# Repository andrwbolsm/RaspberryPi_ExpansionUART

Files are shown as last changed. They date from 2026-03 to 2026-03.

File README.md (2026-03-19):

 
## Context
 
The Raspberry Pi exposes only one hardware UART, which is insufficient when simultaneous communication with multiple devices is required. In this project, each drone in a six-drone swarm uses a dedicated 433 MHz radio transceiver connected over UART. To handle six transceivers from a single Raspberry Pi, a custom expansion board (HAT) was designed using the SC16IS752, natively supported by Linux.
 
A key motivation for moving away from USB was power delivery: the Raspberry Pi's USB ports do not supply enough current to reliably drive multiple radio modules, even through powered hubs. Bypassing USB in favour of direct UART with battery-sourced power resolves this limitation.
 
---
 
## System Architecture
 
```
[ Battery ]
     │
     ├──► [ Voltage Regulator (5V) ] ──► [ SC16IS752 ]
     │                                        │
[ Raspberry Pi ]                       UART A (/dev/ttySC0) ──► Radio transceiver 1
  I²C bus ──────────────────────────►  UART B (/dev/ttySC1) ──► Radio transceiver 2
                                        (stack additional chips for more channels)
```
 
- Power for the SC16IS752 is drawn **directly from the battery** through a regulator, bypassing the Raspberry Pi's USB current limit.
- The I²C bus from the Raspberry Pi controls the chip; Linux automatically exposes each UART as `/dev/ttySC0` and `/dev/ttySC1`.
- Multiple chips can be stacked on the same I²C bus using different A0/A1 addresses, scaling up to 32 UART channels.
 
---
 
## Hardware
 
| Component | Role |
|---|---|
| Raspberry Pi | Main onboard computer (Linux) |
| SC16IS752 | I²C-to-dual-UART bridge chip (2 ch UART + 8 GPIO) |
| 433 MHz radio transceivers | Long-range communication with drones (~400 m through buildings) |
| Voltage regulator | Supplies 5V (≥ 1W) to the chip from the battery |
| Custom HAT PCB | Designed with KiCad; connects directly to the Raspberry Pi GPIO header |
 
The radio modules operate in the **433 MHz band**, each assigned a separate channel to avoid inter-drone interference.
 
---
 
## Repository Structure
 
```
.
├── Code/               # Firmware / communication validation code (C)
├── Projet_Tschema/     # PCB schematic and layout files (KiCad)
└── README.md
```
 
---
 
## Setup
 
### 1. Enable I²C on the Raspberry Pi
 
```bash
sudo raspi-config
# Navigate to: Interfacing Options → I2C → Yes
```
 
### 2. Register the SC16IS752 kernel driver
 
Append to `/boot/config.txt`:
 
```
dtoverlay=sc16is752-i2c,int_pin=24,addr=0x48
# addr changes according to A0/A1 jumper setting — default is 0x48
```
 
Then reboot:
 
```bash
sudo reboot
```
 
### 3. Verify UART devices are exposed
 
```bash
ls /dev/ttySC*
# Expected: /dev/ttySC0  /dev/ttySC1
```
 
---
 
## PCB Design
 
The expansion board is designed in **KiCad** (files in `Projet_Tschema/`). It plugs onto the Raspberry Pi GPIO header and provides:
 
- I²C connection to the SC16IS752
- Battery-sourced regulated 5V power rail for the chip
- UART connectors for each radio transceiver
   
---
 
## Software
 
The firmware (`Code/`, C) handles:
 
1. **UART validation** — confirms Linux correctly enumerates `/dev/ttySC0` and `/dev/ttySC1` after the HAT is mounted.
2. **Communication protocol** — data exchange with each radio transceiver over its dedicated UART channel.
 
---

## Validation Steps
 
1. Mount the HAT and power the SC16IS752 from the battery rail.
2. Confirm UART devices appear: `ls /dev/ttySC*`
3. Run the communication test to validate send/receive on one channel.
 
---
 
## Status
 
> Active development — PCB validation and multi-channel firmware in progress.

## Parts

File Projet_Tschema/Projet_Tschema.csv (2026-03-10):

Reference | Qty | Value | DNP | Exclude from BOM | Exclude from Board | Footprint | Datasheet
C1 | 1 | 0.1uF |  |  |  | Capacitor_SMD:C_0805_2012Metric | ~
C2 | 1 | 22pF |  |  |  | Capacitor_SMD:C_0805_2012Metric | ~
C3 | 1 | 33pF |  |  |  | Capacitor_SMD:C_0805_2012Metric | ~
C4,C5 | 2 | 10uF |  |  |  | Capacitor_SMD:C_0805_2012Metric | ~
D1,D2 | 2 | LED_Filled |  |  |  | LED_SMD:LED_0805_2012Metric | ~
H1,H2 | 2 | Conn_01x06 |  |  |  | Connector_JST:JST_GH_SM06B-GHS-TB_1x06-1MP_P1.25mm_Horizontal | ~
J1 | 1 | Raspberry_Pi_2_3 |  |  |  | Connector_PinHeader_2.54mm:PinHeader_2x20_P2.54mm_Vertical | https://www.raspberrypi.org/documentation/hardware/raspberrypi/schematics/rpi_SCH_3bplus_1p0_reduced.pdf
J2 | 1 | Screw_Terminal_01x02 |  |  |  | Connector_PinHeader_2.54mm:PinHeader_1x02_P2.54mm_Vertical | ~
J3 | 1 | Conn_D42V55F5 |  |  |  | Connector_PinHeader_2.54mm:PinHeader_2x06_P2.54mm_Vertical | ~
L_RXA1,L_RXB1,L_TXA1,L_TXB1 | 4 | LED_Filled |  |  |  | Resistor_SMD:R_0805_2012Metric | ~
R1,R3,R4,R5,R8,R9,R10,R24 | 8 | 1K |  |  |  | Resistor_SMD:R_0805_2012Metric | ~
R2 | 1 | 10K |  |  |  | Resistor_SMD:R_0805_2012Metric | ~
R11,R12,R13 | 3 | 0R |  |  |  | Resistor_SMD:R_0805_2012Metric | ~
R14,R15,R16,R17,R18,R19,R20,R21,R22,R23 | 10 | NC |  |  |  | Resistor_SMD:R_0805_2012Metric | ~
U1 | 1 | SC16IS-752 |  |  |  | Package_SO:TSSOP-28_4.4x9.7mm_P0.65mm | https://www.nxp.com/docs/en/data-sheet/SC16IS752_SC16IS762.pdf
U2 | 1 | AMS1117 |  |  |  | Package_TO_SOT_SMD:SOT-223-3_TabPin2 | http://www.advanced-monolithic.com/pdf/ds1117.pdf
Y1 | 1 | 14.7456M |  |  |  | Crystal:Crystal_SMD_3225-4Pin_3.2x2.5mm | ~

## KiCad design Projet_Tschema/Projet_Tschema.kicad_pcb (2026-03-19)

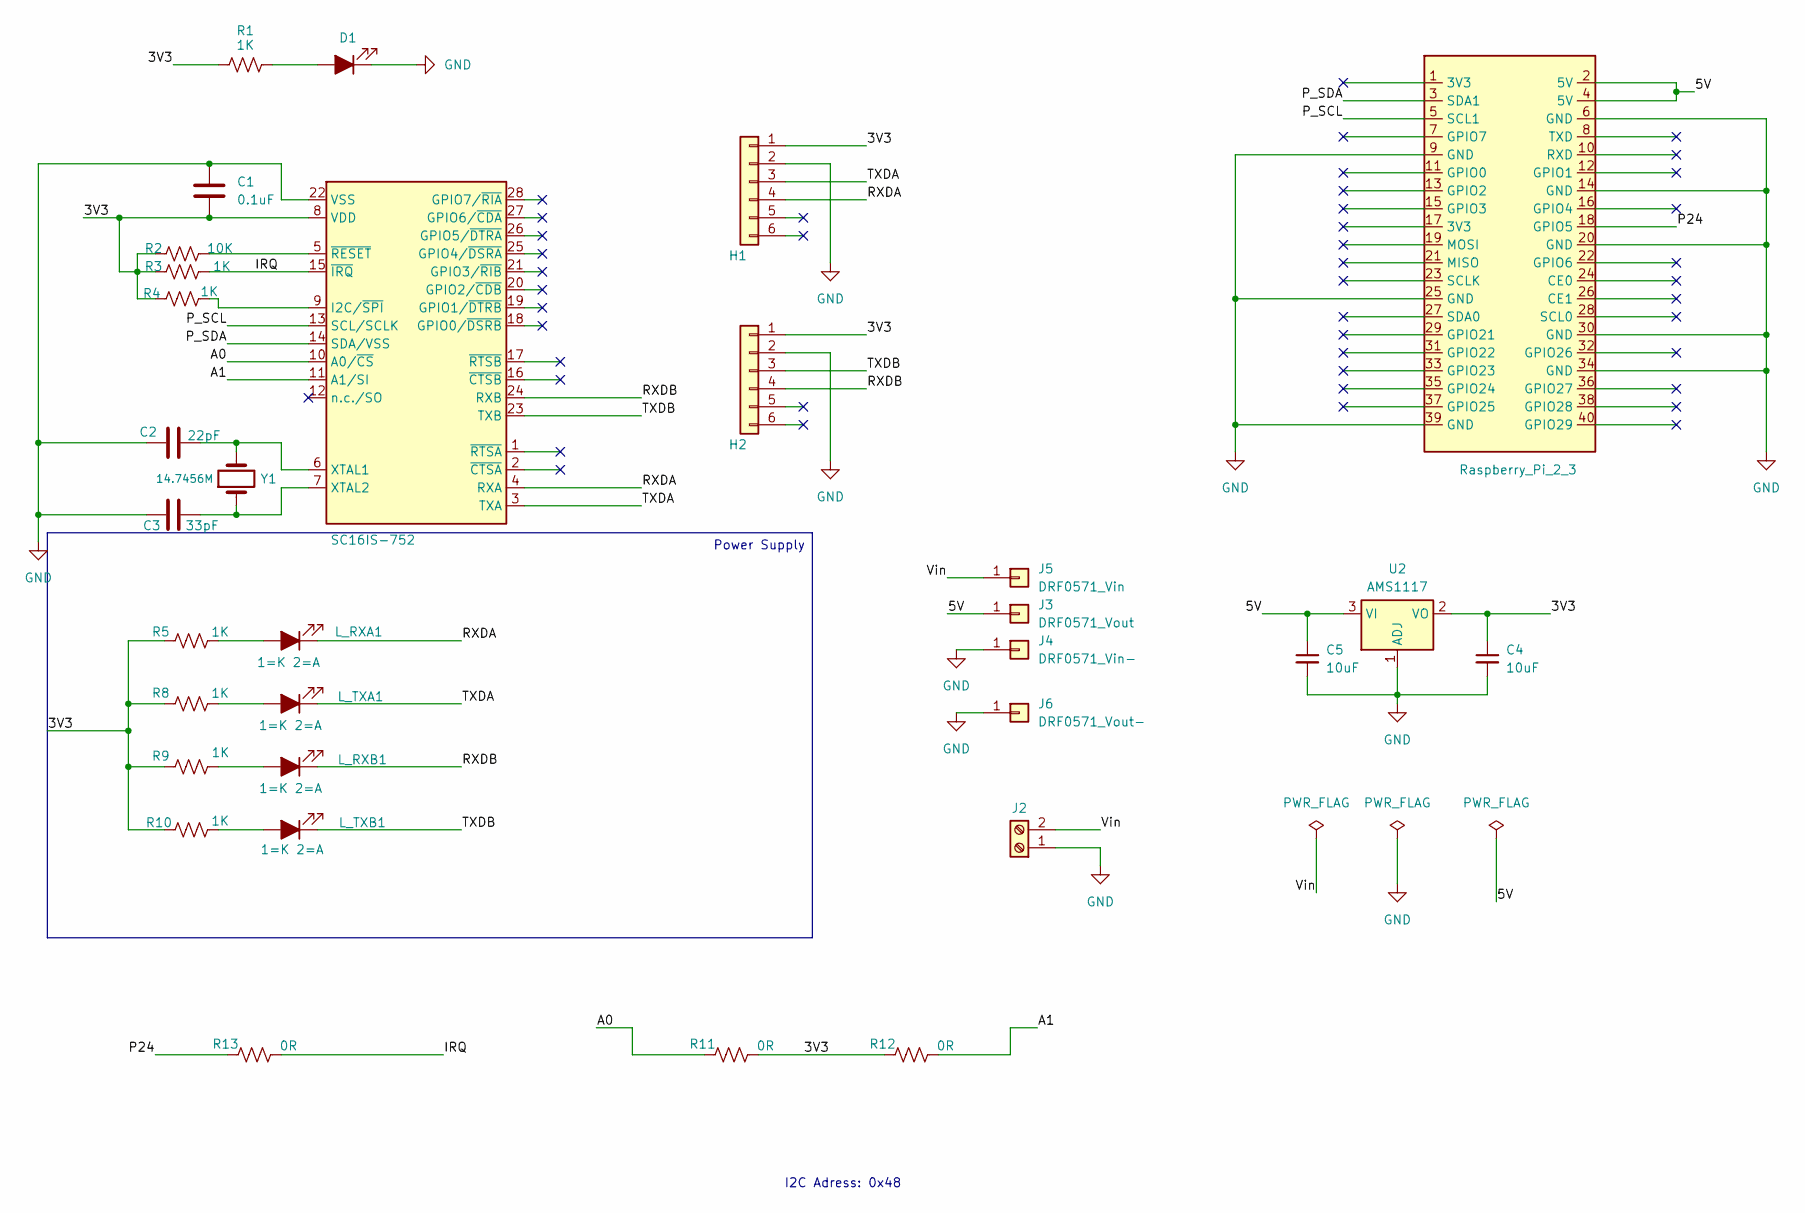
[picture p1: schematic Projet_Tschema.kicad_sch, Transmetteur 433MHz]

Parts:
C1: 0.1uF; C_0805_2012Metric
C2: 22pF; C_0805_2012Metric
C3: 33pF; C_0805_2012Metric
C4, C5: 10uF; C_0805_2012Metric
D1: LED_Filled; LED_0805_2012Metric
H1, H2: Conn_01x06; JST_GH_SM06B-GHS-TB_1x06-1MP_P1.25mm_Horizontal
J1: Raspberry_Pi_2_3; PinHeader_2x20_P2.54mm_Vertical
J2: Screw_Terminal_01x02; PinHeader_1x02_P2.54mm_Vertical
J3: DRF0571_Vout; PinHeader_1x01_P2.54mm_Vertical
J4: DRF0571_Vin-; PinHeader_1x01_P2.54mm_Vertical
J5: DRF0571_Vin; PinHeader_1x01_P2.54mm_Vertical
J6: DRF0571_Vout-; PinHeader_1x01_P2.54mm_Vertical
L_RXA1: LED_Filled; R_0805_2012Metric
L_RXB1: LED_Filled; R_0805_2012Metric
L_TXA1: LED_Filled; R_0805_2012Metric
L_TXB1: LED_Filled; R_0805_2012Metric
R1, R3, R4, R5, R8, R9, R10: 1K; R_0805_2012Metric
R2: 10K; R_0805_2012Metric
R11, R12, R13: 0R; R_0805_2012Metric
U1: SC16IS-752; TSSOP-28_4.4x9.7mm_P0.65mm
U2: AMS1117; SOT-223-3_TabPin2
Y1: 14.7456M; Crystal_HC52-U_Vertical

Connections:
/3V3: C1.2, C4.1, H1.1, H2.1, R1.1, R2.1, R3.1, R4.1, R5.1, R8.1, R9.1, R10.1, R11.2, R12.1, U1.8 (VDD), U2.2 (VO)
/5V: C5.1, J1.2 (5V), J1.4 (5V), J3.1, U2.3 (VI)
/&lt;NO NET&gt;: J1.27 (SDA0)
/A0: R11.1, U1.10 (A0/~CS)
/A1: R12.2, U1.11 (A1/SI)
/IRQ: R3.2, R13.2, U1.15 (~IRQ)
/P24: J1.18 (GPIO5), R13.1
/P_SCL: J1.5 (SCL1), U1.13 (SCL/SCLK)
/P_SDA: J1.3 (SDA1), U1.14 (SDA/VSS)
/RXDA: H1.4, L_RXA1.1 (K), U1.4 (RXA)
/RXDB: H2.4, L_RXB1.1 (K), U1.24 (RXB)
/TXDA: H1.3, L_TXA1.1 (K), U1.3 (TXA)
/TXDB: H2.3, L_TXB1.1 (K), U1.23 (TXB)
/Vin: J2.2, J5.1
GND: C1.1, C2.2, C3.2, C4.2, C5.2, D1.1 (K), H1.2, H2.2, J1.6 (GND), J1.9 (GND), J1.14 (GND), J1.20 (GND), J1.25 (GND), J1.30 (GND), J1.34 (GND), J1.39 (GND), J2.1, J4.1, J6.1, U1.22 (VSS), U2.1 (ADJ)
unnamed: D1.2 (A), R1.2
unnamed: L_RXA1.2 (A), R5.2
unnamed: L_RXB1.2 (A), R9.2
unnamed: L_TXA1.2 (A), R8.2
unnamed: L_TXB1.2 (A), R10.2
unnamed: R4.2, U1.9 (I2C/~SPI)
unnamed: C2.1, U1.6 (XTAL1), Y1.2
unnamed: C3.1, U1.7 (XTAL2), Y1.1
unnamed: R2.2, U1.5 (~RESET)

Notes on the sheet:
I2C Adress: 0x48
Power Supply

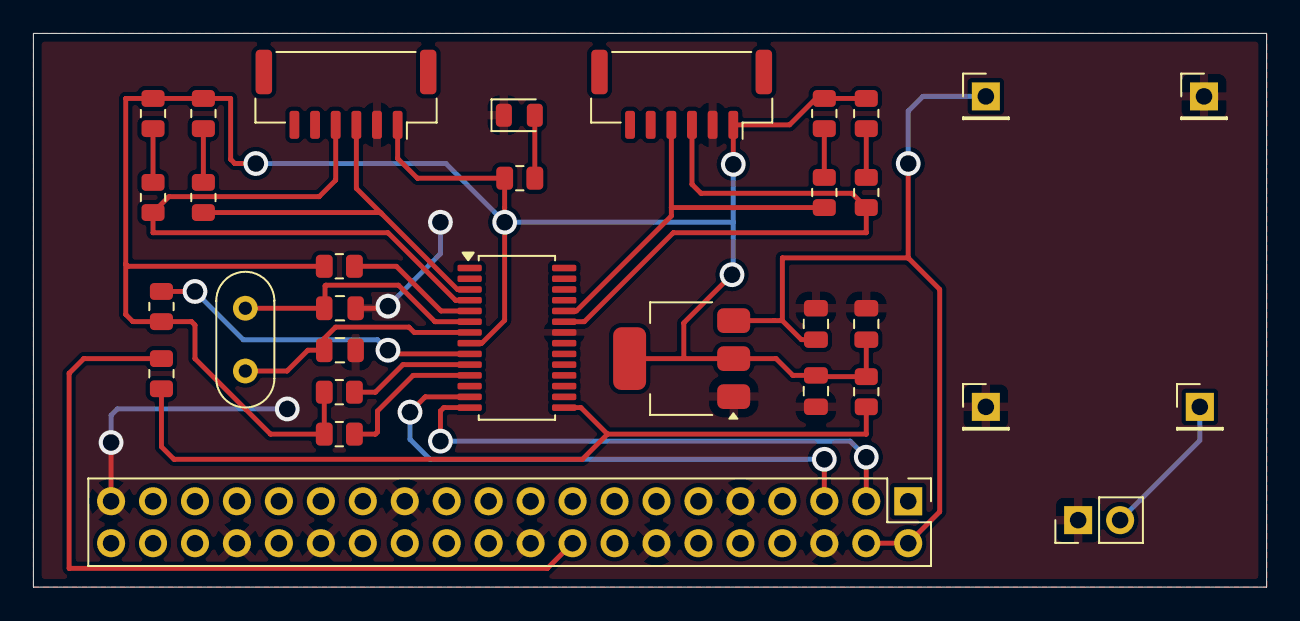
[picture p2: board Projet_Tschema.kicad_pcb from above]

Board: 2 copper layers, 74.7 x 33.5 mm, 32 parts (0 on the bottom side), 23 nets.

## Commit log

2026-02-27 Premier commit : initialisation du projet
    [Projet_Tschema.csv, Projet_Tschema.kicad_pcb, Projet_Tschema.kicad_sch]
2026-03-12 first version finished
    [Projet_Tschema.kicad_pcb, Projet_Tschema.kicad_sch]
2026-03-17 routes updated
    [Projet_Tschema.kicad_pcb, Projet_Tschema.kicad_sch]
2026-03-19 Final adjustments for gerber generation
    [Projet_Tschema.kicad_pcb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]
